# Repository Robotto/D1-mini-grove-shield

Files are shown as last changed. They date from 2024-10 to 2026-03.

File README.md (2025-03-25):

# The boards look like this:

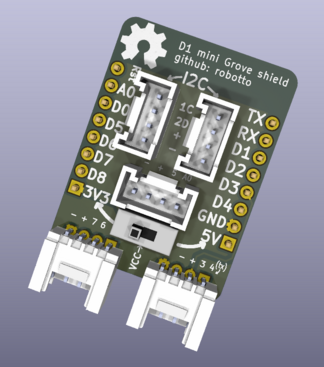
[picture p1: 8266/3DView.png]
3D View of ESP8266 Board

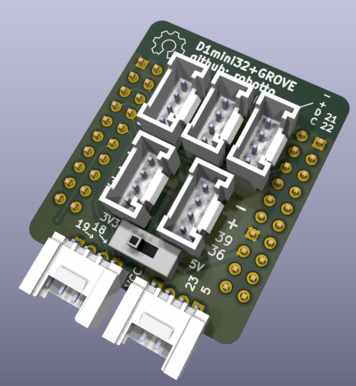
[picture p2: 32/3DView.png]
3D View of ESP32 Board


# Kicanvas links:

## [ESP8266 version](https://kicanvas.org/?github=https%3A%2F%2Fgithub.com%2FRobotto%2FD1-mini-grove-shield/tree/main/8266)

## [ESP32 version](https://kicanvas.org/?github=https%3A%2F%2Fgithub.com%2FRobotto%2FD1-mini-grove-shield/tree/main/32)

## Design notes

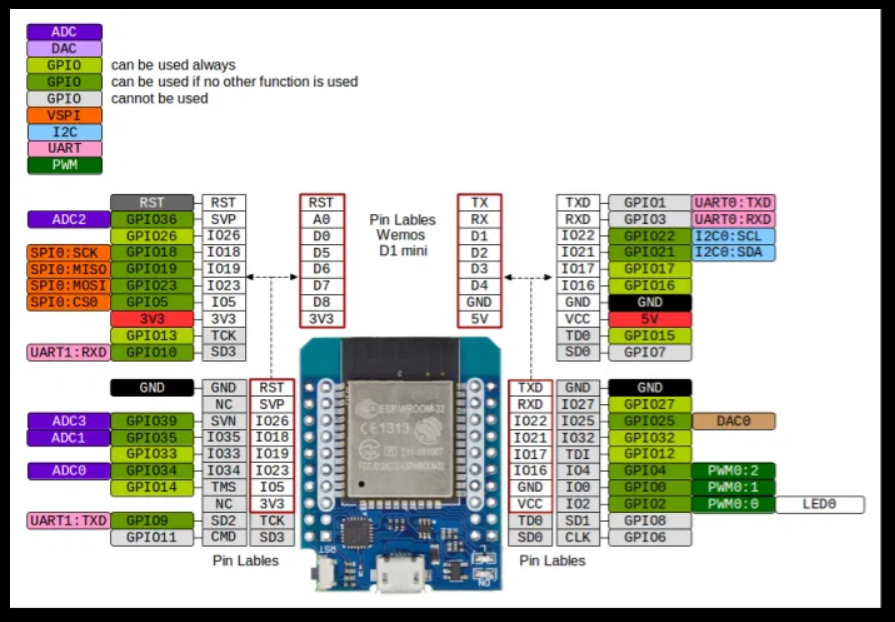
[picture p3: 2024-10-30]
D1_mini_ESP32_pinout.png

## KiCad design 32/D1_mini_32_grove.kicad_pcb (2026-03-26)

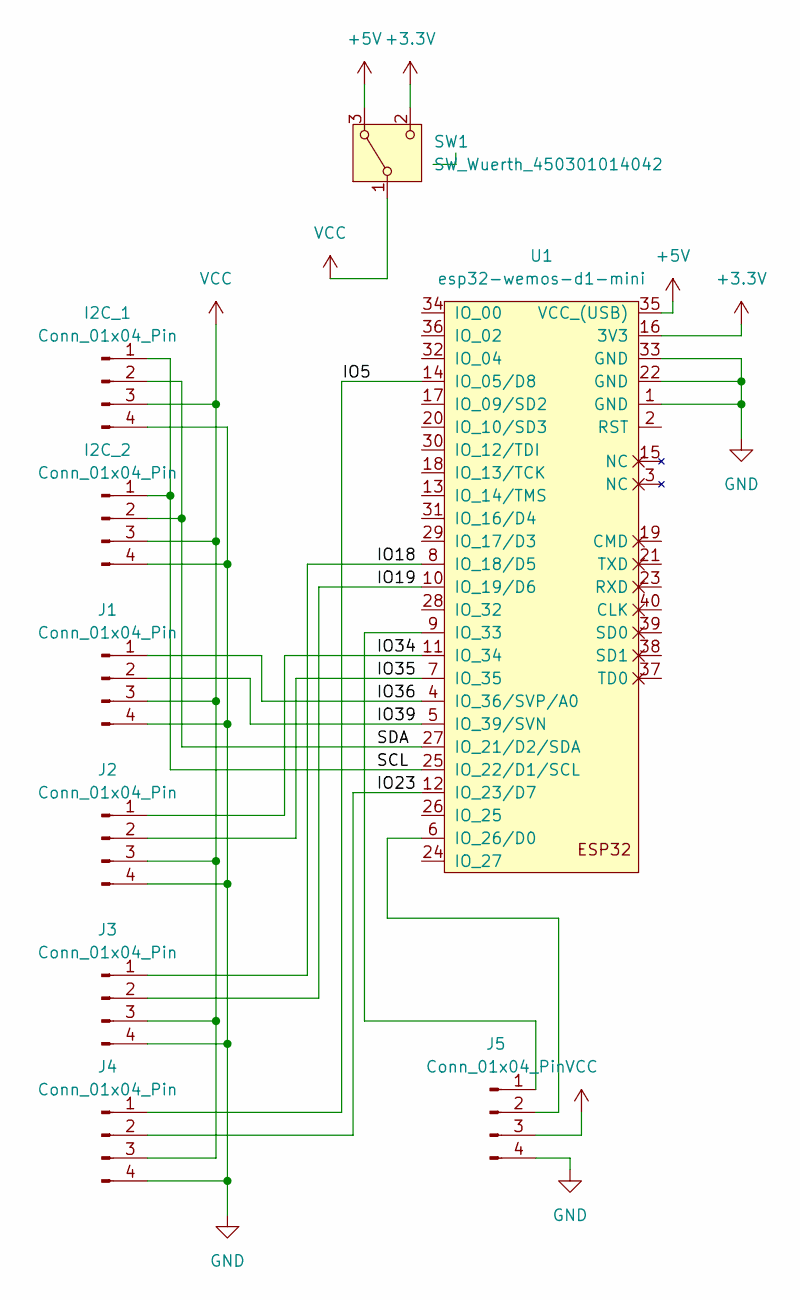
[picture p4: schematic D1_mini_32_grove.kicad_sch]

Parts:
I2C_1, I2C_2: Conn_01x04_Pin; NS-Tech_Grove_1x04_P2mm_Vertical
J1, J2, J3, J4, J5: Conn_01x04_Pin; NS-Tech_Grove_1x04_P2mm_Vertical
SW1: SW_Wuerth_450301014042; SW_Slide-03_Wuerth-WS-SLTV_10x2.5x6.4_P2.54mm
U1: esp32-wemos-d1-mini

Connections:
+3.3V: SW1.2 (C), U1.16 (3V3)
+5V: SW1.3 (A), U1.35 (VCC_(USB))
/IO5: J4.1, U1.14 (IO_05/D8)
/IO18: J3.1, U1.8 (IO_18/D5)
/IO19: J3.2, U1.10 (IO_19/D6)
/IO23: J4.2, U1.12 (IO_23/D7)
/IO34: J2.1, U1.11 (IO_34)
/IO35: J2.2, U1.7 (IO_35)
/IO36: J1.1, U1.4 (IO_36/SVP/A0)
/IO39: J1.2, U1.5 (IO_39/SVN)
/SCL: I2C_1.1, I2C_2.1, U1.25 (IO_22/D1/SCL)
/SDA: I2C_1.2, I2C_2.2, U1.27 (IO_21/D2/SDA)
GND: I2C_1.4, I2C_2.4, J1.4, J2.4, J3.4, J4.4, J5.4, U1.1 (GND), U1.22 (GND), U1.33 (GND)
unnamed: J5.1, U1.9 (IO_33)
unnamed: J5.2, U1.6 (IO_26/D0)
VCC: I2C_1.3, I2C_2.3, J1.3, J2.3, J3.3, J4.3, J5.3, SW1.1 (B)

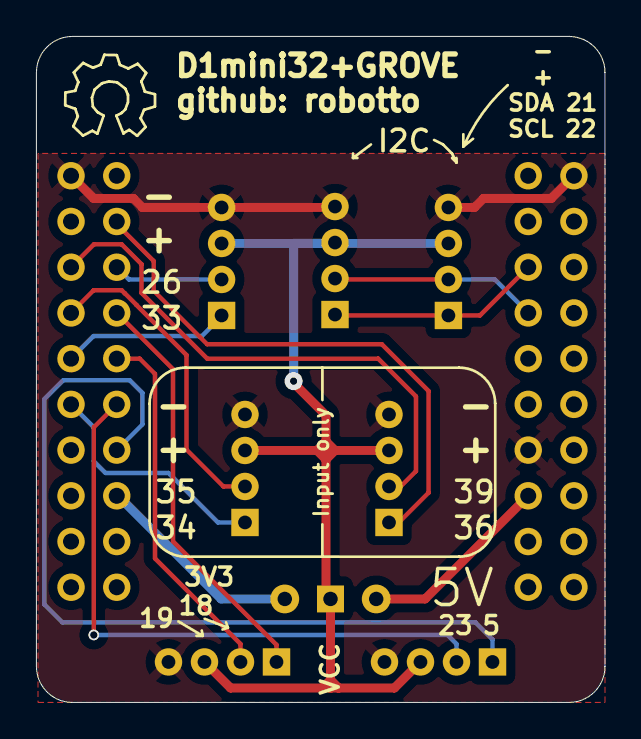
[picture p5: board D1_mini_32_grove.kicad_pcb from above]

Board: 2 copper layers, 31.6 x 37.0 mm, 9 parts (0 on the bottom side), 16 nets.

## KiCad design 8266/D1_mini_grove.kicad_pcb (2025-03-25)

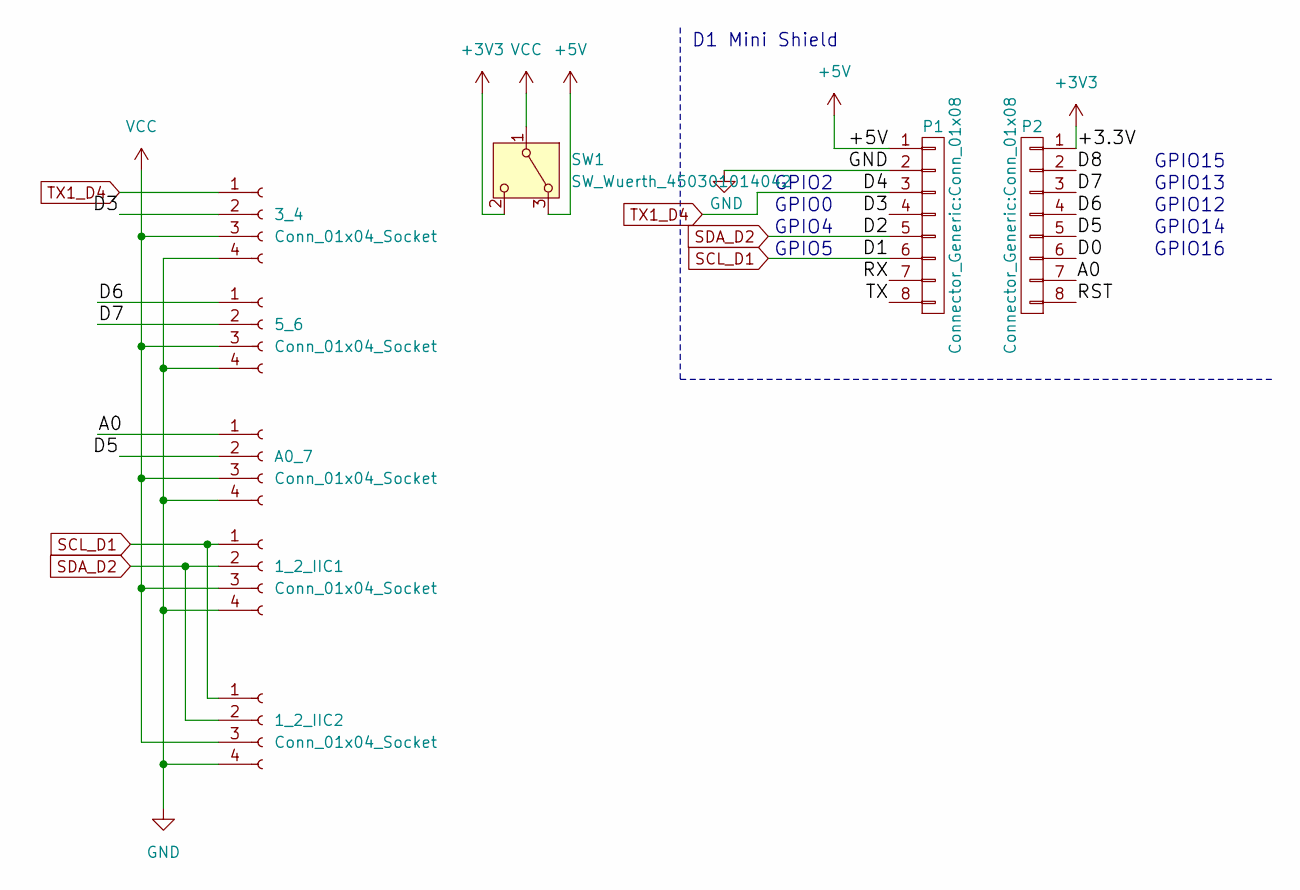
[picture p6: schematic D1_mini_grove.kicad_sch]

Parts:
1_2_IIC1, 1_2_IIC2, 3_4, 5_6: Conn_01x04_Socket; NS-Tech_Grove_1x04_P2mm_Vertical
A0_7: Conn_01x04_Socket; NS-Tech_Grove_1x04_P2mm_Vertical
P1, P2: Connector_Generic:Conn_01x08; D1_mini_Pin_Header
SW1: SW_Wuerth_450301014042; SW_Slide-03_Wuerth-WS-SLTV_10x2.5x6.4_P2.54mm

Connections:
+3V3: P2.1, SW1.2 (C)
+5V: P1.1, SW1.3 (A)
/A0: A0_7.1, P2.7
/D0: P2.6
/D3: 3_4.2, P1.4
/D5: A0_7.2, P2.5
/D6: 5_6.1, P2.4
/D7: 5_6.2, P2.3
/D8: P2.2
/RST: P2.8
/RX: P1.7
/TX: P1.8
GND: 1_2_IIC1.4, 1_2_IIC2.4, 3_4.4, 5_6.4, A0_7.4, P1.2
SCL_D1: 1_2_IIC1.1, 1_2_IIC2.1, P1.6
SDA_D2: 1_2_IIC1.2, 1_2_IIC2.2, P1.5
TX1_D4: 3_4.1, P1.3
VCC: 1_2_IIC1.3, 1_2_IIC2.3, 3_4.3, 5_6.3, A0_7.3, SW1.1 (B)

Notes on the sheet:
GPIO12
GPIO2
GPIO16
GPIO13
GPIO4
GPIO15
D1 Mini Shield
GPIO5
GPIO0
GPIO14

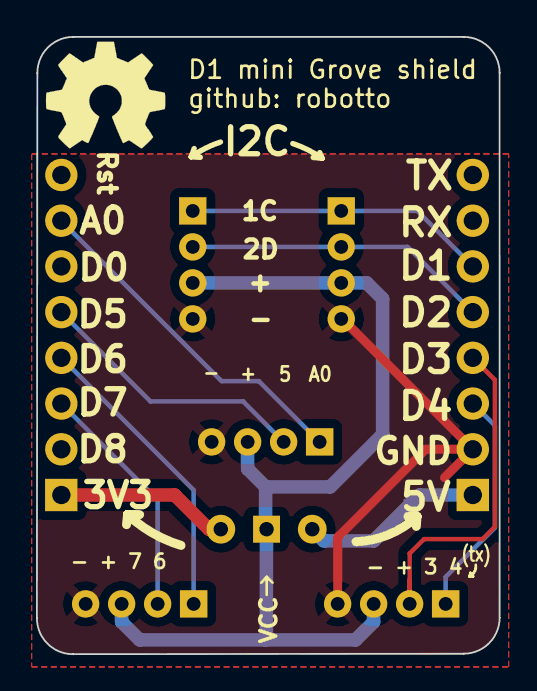
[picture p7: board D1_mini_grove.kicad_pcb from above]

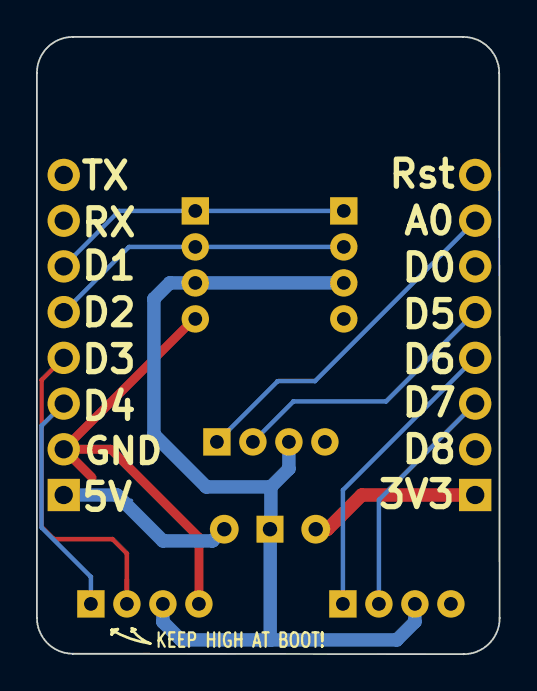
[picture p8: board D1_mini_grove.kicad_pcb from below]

Board: 2 copper layers, 25.7 x 34.3 mm, 8 parts (2 on the bottom side), 12 nets.

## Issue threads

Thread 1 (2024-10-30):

Topsilk pin numbers is still wrong ...

Robotto, 2024-10-30:
Well, this is awkward 😬

Robotto, 2024-10-30:
5<->7

Closed 2024-10-31.

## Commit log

2024-10-30 Added 3D view of board
2024-10-30 forgot to commit footprint library table
2024-10-31 Topsilk rearranged, shoud fix #1
    [D1_mini_grove.kicad_pcb]
2024-11-07 flipped some stuff around
    [D1_mini_grove.kicad_pcb]
2024-11-07 Fiddled with grove connector footprint silk
2024-11-07 Finetuned some layout
    [D1_mini_grove.kicad_pcb]
2024-11-17 moved ESP8266 project to subfolder, getting ready for ESP32 version
    [D1_mini_grove.kicad_pcb, D1_mini_grove.kicad_sch]
2024-11-17 started doing the ESP32 version, don't trust anything yet
    [D1_mini_32_grove.kicad_pcb, D1_mini_32_grove.kicad_sch]
2024-11-18 First draft of 32 board ready for testrun
    [D1_mini_32_grove.kicad_pcb, D1_mini_32_grove.kicad_sch]
2024-11-18 last commit din't take because i'm messing around with upstream stuff
    [D1_mini_32_grove.kicad_pcb]
2024-11-18 moved small things, sent gerbers to pcbway
    [D1_mini_32_grove.kicad_pcb]
2024-11-28 bigger holes for pin header rows
    [D1_mini_32_grove.kicad_pcb]
2025-03-23 Added a switch for VCC selector instead of solder bridge.. its tight but itll work
    [D1_mini_32_grove.kicad_pcb, D1_mini_32_grove.kicad_sch, D1_mini_grove.kicad_pcb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]
2025-03-24 Messing with silkscreen, mostly
    [D1_mini_32_grove.kicad_pcb, D1_mini_grove.kicad_pcb]
2025-03-24 The 32board had room for one more grove connector... finetuned some 3D stuff too
    [D1_mini_32_grove.kicad_pcb, D1_mini_32_grove.kicad_sch]
2025-03-24 Production run for 8266 board as well.
    [D1_mini_grove.kicad_pcb]
2025-03-25 Set 3D model dir to relaive path, flipped entire 8266 board around so it sits right in my mind
    [D1_mini_grove.kicad_pcb]
2025-03-25 trying stuff with step file previews
    [D1_mini_32_grove.step, D1_mini_grove.step]
2025-03-25 3D stuff
    [D1_mini_32_grove.kicad_pcb, D1_mini_32_grove.step, D1_mini_grove.step]
2025-09-29 Second production run
    [D1_mini_32_grove.kicad_pcb]
2025-09-29 Safety commit
    [D1_mini_32_grove.kicad_pcb]
2026-03-05 Slighly modified layout for 3rd production run
    [D1_mini_32_grove.kicad_pcb]
2026-03-26 Added silkscreen info about input only pins
    [D1_mini_32_grove.kicad_pcb, D1_mini_32_grove.kicad_sch]
